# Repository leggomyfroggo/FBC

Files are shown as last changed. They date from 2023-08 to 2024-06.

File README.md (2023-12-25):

# Frog Boy Color
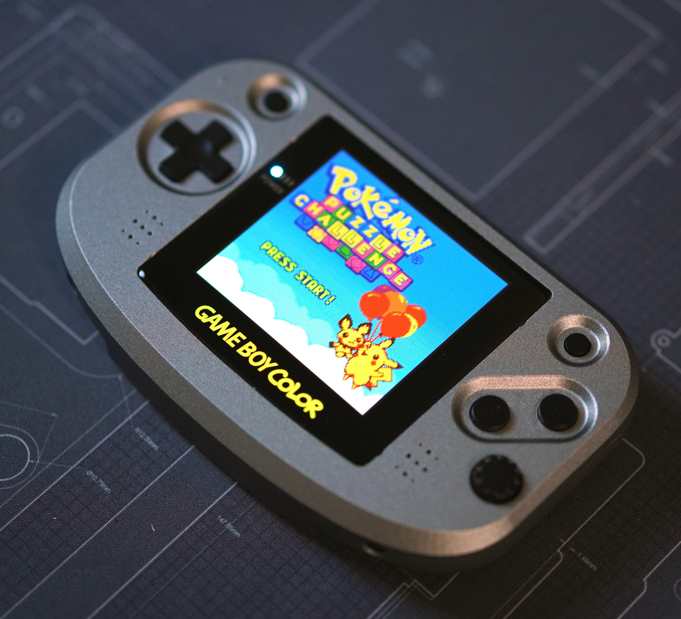
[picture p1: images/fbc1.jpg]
Frog Boy Color

The Frog Boy Color is a reimagining of the Nintendo Game Boy Color, aka the greatest Game Boy ever made. Taking the best parts of a modded GBC -- large screen with correct aspect ratio, no cartridges sticking out, etc -- and marrying them to a horizontal format ala the GBA, the Frog Boy is the realization of exactly the kind of Game Boy I've wanted since I initially jumped into modding. 

Features include:
- All features of the original GBC minus IR -- use of GB/GBC cartridges, link cable, headphone jack, etc.
- Compatibie with popular laminated backlit screen kits from FunnyPlaying and others
- Dual speakers for stereo sound
- Internal battery rechargable via USB-C
- Tactile buttons like the GBA SP
- Two stage battery indicator

The following is a guide on how you can build your very own Frog Boy.

# Attribution
Before getting to the build, it's important to provide attribution to the other project(s) that have in part gone into the Frog Boy Color.
- **[Gekkio/gekkio-kicad-libs](https://github.com/Gekkio/gekkio-kicad-libs)**: The FBC incorporates several of Gekkio's excellent kicad symbols and footprints, including for the CPU, RAM(modified), link port, and cartridge connector(modified). Huge thanks to Gekkio for making these available for others to use!

# Disclaimer/Warning/For the love of God, read this
The Frog Boy is not an easy project, nor is it a professional product, and as such there are some things to keep in mind as you consider building one.

Assembly of the Frog Boy requires intermediate-advanced skills in soldering and electronics tinkering, including:
- Desoldering/soldering of large ICs
- Desoldering of through hole parts
- Soldering of small surface mount devices
- Soldering of leadless ICs, for example the TSP61202
- Proficiency with a multimeter for troubleshooting and validation
This is in no way a project for beginners, and if you don't have experience with the above, I highly recommend starting smaller -- solder practice kits are cheap and easily available.

Along with needing the requisite skills, there is a very real possibility that you will irreparably damage either your donor Game Boy Color, or the resulting Frog Boy. Even the most skilled among us make mistakes, but it's important to keep in mind your own limits to avoid heartache and sorrow.

I am in no way a professional electrical engineer. All of my skills are self taught, or learned from other members of the modding community. While I have taken common sense measures to ensure that the Frog Boy is functional and safe, I can not guarantee that each and every decision made is correct. Build at your own discretion.

In summary, build at your own risk. I am not liable for any damage or injury caused by your insatiable need to build a Game Boy named after an amphibian.

# Recommended Equipment
At a bare minimum, you should have:
- Temperature controlled soldering iron. I recommend the Pinecil as a great entry level option.
- Multimeter for troubleshooting. Any cheap digital multimeter from Amazon should do fine.
- Solder sucker for removing cartridge slot from donor GBC
- No clean flux

I highly recommend also having the following:
- A hot plate or hot air station for the QFN ICs, desoldering parts from GBC, etc
- Solder wick

# Bill of Materials(BOM)
Below is the breakdown of all materials you will need to build a Frog Boy Color.
## Build Components
- **PCB:** The Frog Boy Color uses a fully custom PCB designed to fit within the custom shell while still using many of the original GBC components. The following board parameters should be used:
  - **Layers:** 4-layer
  - **Thickness:** 1mm
  - **Surface finish:** HASL or ENIG
  - **Color:** Whatever you want
  - [**Order from PCBWay**](https://www.pcbway.com/project/shareproject/Frog_Boy_Color_PCB_29101ba1.html)
- **Shell:** The shell for the Frog Boy Color is a fully custom design, and suitable for both resin printing and CNC machining. NOTE: When ordering in resin, there is a risk of the thin areas around the buttons and d-pad to break during fabrication.
  - [**Order from PCBWay**](https://www.pcbway.com/project/shareproject/Frog_Boy_Color_PCB_29101ba1.html)
- **Volume Wheel:** The volume wheel is another custom piece, and is intended to be CNC machined. Resin printing will probably work, but is untested.
  - Step file available in `Accessories` folder so you can get it produced where you wish.
  - [**Order from PCBWay**](https://www.pcbway.com/project/shareproject/Frog_Boy_Color_PCB_29101ba1.html)
- **Battery Clips:** Clips for the batteries to keep them in place. Left and right clips are different, and you'll want one of each. Not stricly necessary, but highly recommended. Should be printed in SLS/MJF nylon.
  - STL files available in `Accessories` folder so you can get them produced where you wish.
  - [**Order from PCBWay**](https://www.pcbway.com/project/shareproject/Frog_Boy_Color_PCB_29101ba1.html)
- **Light pipe:** An optional light pipe can be added for the indicator LEDs to better diffuse them. An STL for this can be found in `Accessories`. This should be printed with clear filament or resin.
  - STL files available in `Accessories` folder so you can get them produced where you wish.
  - [**Order from PCBWay**](https://www.pcbway.com/project/shareproject/Frog_Boy_Color_PCB_29101ba1.html)
- **Screws:** The shell is designed to be put together using 13 x M2 4mm machine screws with flat tops. For builds using a resin printed front shell, the cartridge shield screws can likely be reused for that purpose, which cuts M2 screws required to 9. Options:
  - **450pcs M2 M2.5 M3 Screw Kit:** [From Amazon](https://www.amazon.com/gp/product/B07TDHZJLL/)
- **Cartridge shield:** The metal cartridge shield from the GBC is used here for the same purpose. This can be sourced from your donor console, or from any aftermarket shell.
- **Buttons:** The Frog Boy Color uses buttons from the Game Boy Advance SP, either OEM or aftermarket. You will need a complete set, including the brightness button which is repurposed here as the power button. Some suggested buttons:
  - **FunnyPlaying:** [From RGRS](https://retrogamerepairshop.com/collections/gba-sp-buttons/products/funnyplaying-game-boy-advance-sp-buttons)
  - **RetroCNC(membrane version):** [From RGRS](https://retrogamerepairshop.com/collections/gba-sp-buttons/products/new-game-boy-sp-metal-buttons-by-retrocnc)
- **Membranes:** Similarly, the membranes used are also from the Game Boy Advance SP. You will need two sets of these in order to get two brightness button membranes for start/select. Some suggested membranes:
  - **FunnyPlaying:** [From RGRS](https://retrogamerepairshop.com/collections/gba-sp-buttons/products/funnyplaying-game-boy-advance-sp-silicone-pads)
- **Screen:** The FunnyPlaying laminated Q5 screen -- or a laminated Q5 from another manufacturer with the same total assembly thickness, such as from Gameneissance -- must be used in order to fit within the completed unit. Suggested options:
  - FunnyPlaying laminated Q5 screen + driver board: [From RGRS](https://retrogamerepairshop.com/collections/gbc-displays/products/funnyplaying-game-boy-color-2-0-q5-ips-laminated-backlight-kit)
  - FunnyPlaying laminated Q5 screen only: [From RGRS](https://retrogamerepairshop.com/collections/gbc-displays/products/funnyplaying-game-boy-color-2-0-q5-ips-laminated-lcd-replacement-screen-only)
- **Screen driver board:** For the screen driver board, you have two options:
  - FunnyPlaying GBC Retro Pixel 2.0 laminated IPS kit. This is the simplest option, as it can be purchased with the screen, and can be installed as is. The caveat is that the touch sensor will not work if you choose to install in an aluminum shell, and you'll need to connect the button controls.
    - FunnyPlaying driver board: [From FunnyPlaying](https://funnyplaying.com/products/gbc-retro-pixel-ips-2-0-replacement-ribbon)
  - Super OSD Retro Pixel IPS kit. An alternative to the FunnyPlaying kit with additional options. The downside is that you generally can not purchase it with a suitable laminated screen, and the board-to-board ribbon cable is rather stiff, which can cause assembly issues. The latter can be mitigated by using the custom replacement found under the `Accessories` folder.
    - Super OSD kit(for driver board only, screen too thick): [From RGRS](https://retrogamerepairshop.com/collections/gbc-displays/products/game-boy-color-laminated-q5-xl-ips-backlight-with-osd)
- **Batteries:** The Frog Boy Color can be built with either one or two 802040 LiPo pouch cells. One battery is a simpler arrangement, at the expense of battery life. Two batteries are more complicated, as you'll be required to balance two cells prior to assembly, but with the benefit of roughly double the battery life.

  I also highly recommend printing/ordering the optional battery clips in the `Accessories` folder. They register with holes on each side of the PCB, and provide a nice clip and standoff for each of the batteries. Can be cheaply printed in SLS nylon from JLCPCB, PCBWay, etc.

  NOTE: LiPo batteries can be dangerous if mishandled. NEVER use unprotected cells. It's always safer to use one cell if you're unsure of your ability to properly balance two cells.
  Purchase options:
  - 802040 cell: [From AliExpress](https://www.aliexpress.us/item/3256802244810488.html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)
 
## Shell Ordering Notes
### CNC Machining
- When ordering the front and back shell, make sure you check the box indicating that you need tapped threads. Thread tapping information is already included in the technical drawings.
- Colors for aluminum shells are found under certain "Surface finish" options, such as anodizing.
### Resin Printing
- In the order notes, ask for the shell to be "printed at 99.5% scale on all axes". Resin has a tendency to shrink as it cures, and printers will often overscale to account for this.
- For transparent resin, colors can be selected when choosing dying from the "Surface finish" options.

## PCB Components
- **Harvested GBC Parts:** You will need a donor GBC of revision CPU-05 or before -- CPU-06 revisions will NOT work -- that retains the following components in working order:
  - CPU
  - RAM
  - Crystal
  - Link port
  - Cartridge slot
- **New parts:** The full BOM for the Frog Boy Color be found in the repo, `BOM.xlsx`. Most parts are available from Mouser through a shared project. USB-C connector is available from LCSC. Most parts should be available from most other large distributors in case you want to build out your own cart. Some options:
  - Mouser: [Shared Project](https://www.mouser.com/ProjectManager/ProjectDetail.aspx?AccessID=2927c2105f)
  - LCSC: [USB-C connector](https://www.lcsc.com/product-detail/USB-Connectors_Korean-Hroparts-Elec-TYPE-C-31-M-12_C165948.html)

# Recommended Assembly Procedure
At this point, if you feel confident in your skills, you can proceed with the complete build from PCB to final unit -- assembly after building the PCB is relatively straightforward.

However, I've devised an assembly strategy after assembling a few units that will allow you to check your work along the way, and I highly recommend that you follow along.
## PCB Assembly
### 1. Assembling and testing power circuitry
The power circuitry consists of regulated 5V(TPS61202) and 3.3V(MCP1799T) rails. Start by populating all of the components in the red box on this diagram:

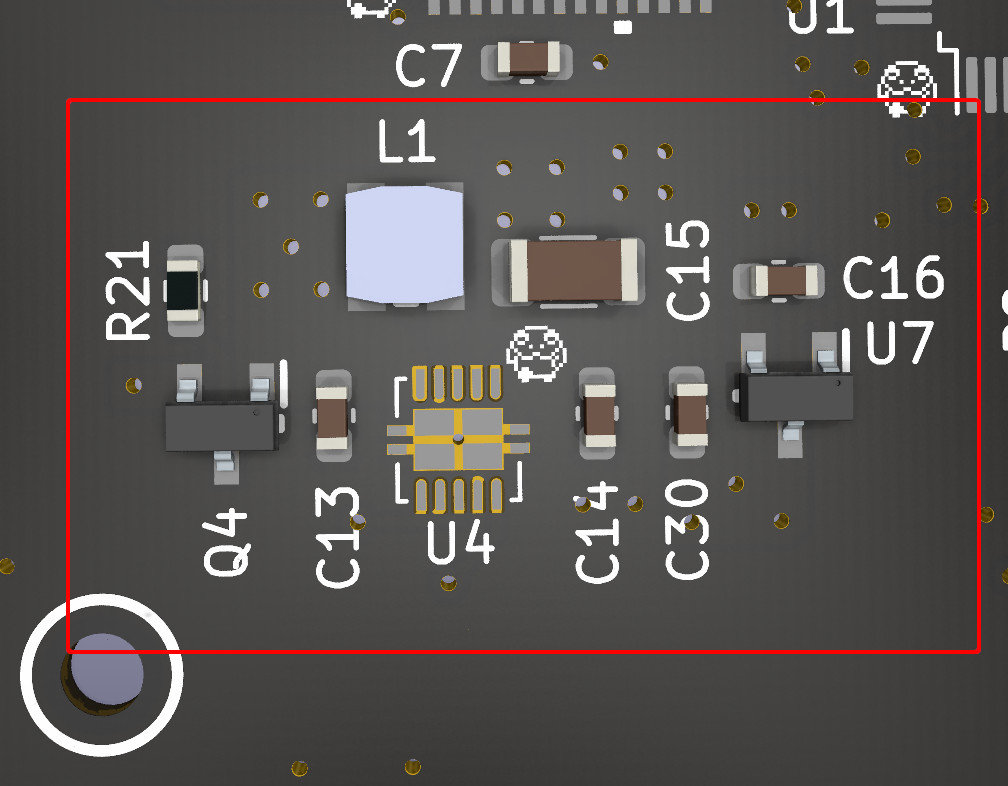
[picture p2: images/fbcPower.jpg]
Power circuitry


You'll then want to test these components to verify that the 5V and 3.3V rails are working correctly. Start by connecting one of your LiPo cells to the VCC1 test pad and pin 32(GND) on the cart slot -- I highly recommend using a multimeter in continuity mode to confirm that these points are not shorted.

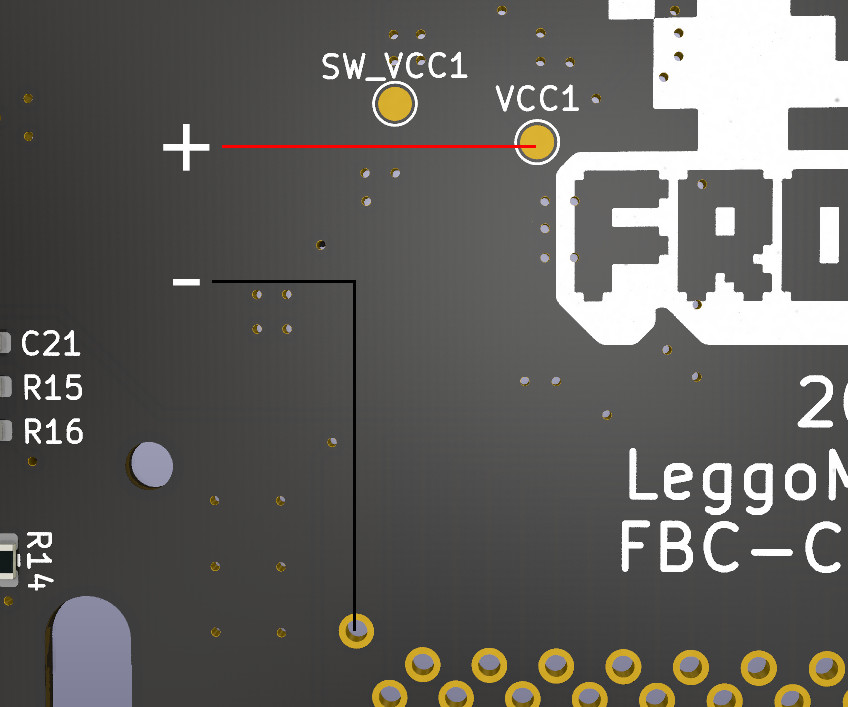
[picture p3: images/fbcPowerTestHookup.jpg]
Battery hook up points


Next, with your meter in DC voltage mode, do the following two tests to verify that the 5V and 3.3V rails are outputting the expected voltage.

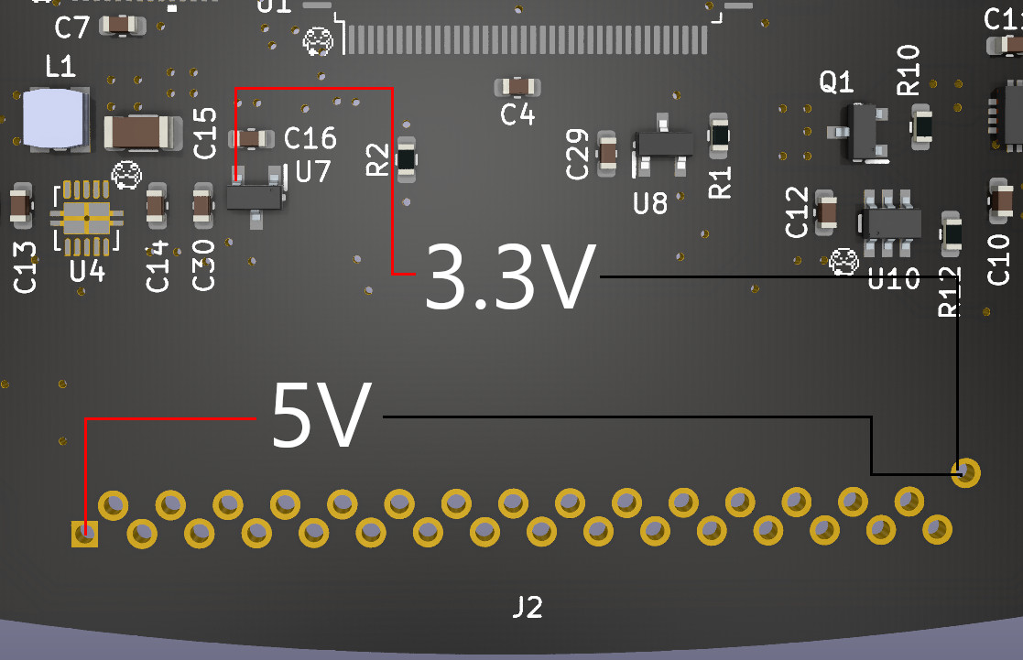
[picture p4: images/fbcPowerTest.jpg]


If everything looks good, you're ready to proceed to the next step.
### 2. Assembling and testing battery charging circuitry
At the heart of the battery charging circuit is the BQ24072TRGTR, which provides both battery charging and power path management -- the latter allows for simultaneous charge and play. Alongside the charging circuitry is a soft latching power circuit, that allows for the use of a momentary push button switch to control power, in contrast to the GBC's slide switch.

Again, start by populating the components indicated below:

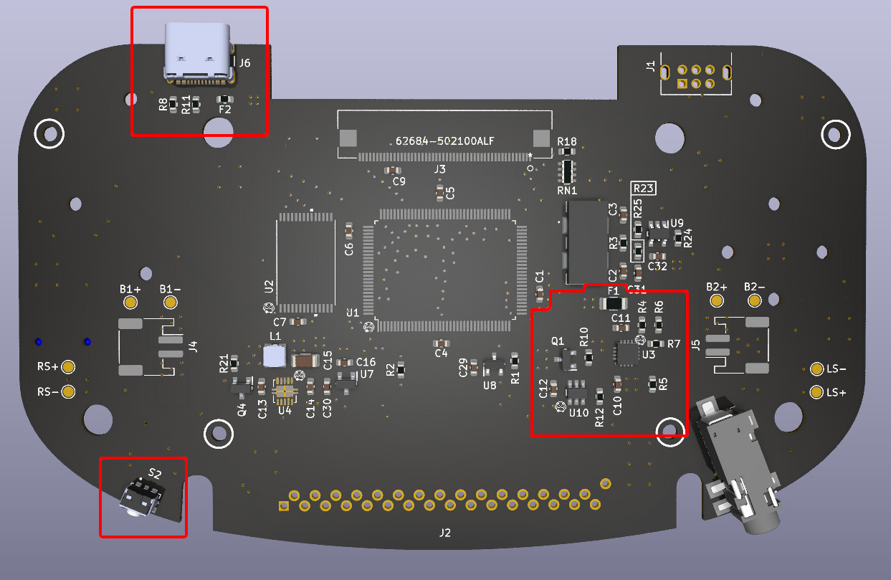
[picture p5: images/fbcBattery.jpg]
Battery and power switch circuitry


Now that the battery circuitry is assembled, a battery can be connected to one of the designated spots for integration testing of the entire power system, e.g B1+ and B1-. At this point, consider the system live any time a battery is connected -- do not do any soldering without first disconnecting all batteries. 

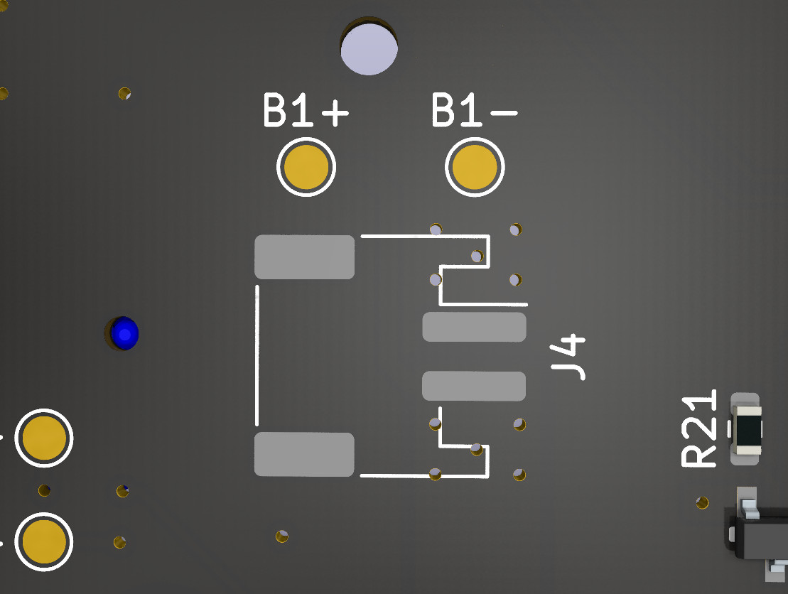
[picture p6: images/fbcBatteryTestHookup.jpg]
Hook up spot for battery 1


Once a battery is connected, put your meter into DC voltage mode and perform the following tests. 

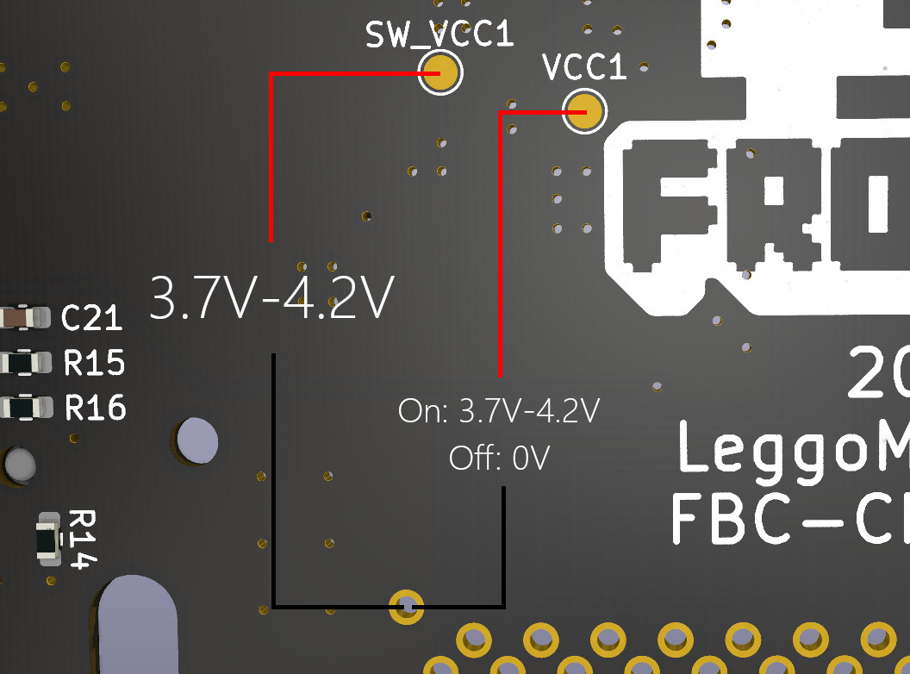
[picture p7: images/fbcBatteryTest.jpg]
Tests for verifying the battery circuitry


For context, SW_VCC1 is live regardless of power state, and should read roughly the same voltage as the battery at all times. VCC1 is the output of the power switch, and should read 0V when the system is off, and roughly battery voltage when the system is on. Press the power switch to cycle between off and on and take measurements to verify that VCC1 reads the correct values. Now is also a good time to verify that your 5V and 3.3V power rails come up when the system is on.

At this point, assuming everything reads correctly, you can be reasonably certain nothing will get fried, and can proceed to the next step. We'll verify battery charging at a later time.

### 3. Installing core GBC pieces
At this point we get to the heart of the system, which is composed of the CPU, RAM, crystal, reset circuitry, display connector, and their support circuitry. The following components should be populated:

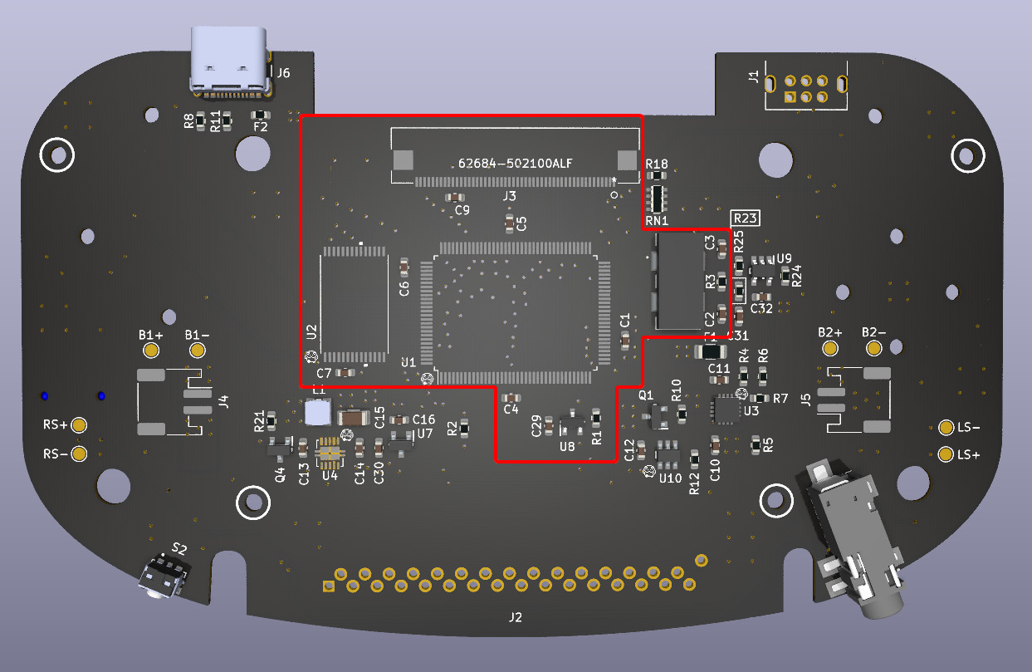
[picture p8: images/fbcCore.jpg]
Core components


With the core components populated at this point, you should now have a semi-functional Frog Boy. To test, connect a battery like in step 2, plug in your screen kit of choice, and power on the system. You should be greeted with the iconic GBC boot screen.

#### Troubleshooting:
This is where things might start to go off the rails, given the number of pins on each of these components. Even one floating pin can cause noticeable problems. Here are some potential problems and solutions.

- **Black screen:** Might indicate a short or floating pin on any of the installed components. Verify all of the power measurements from steps 1 and 2 to rule out major shorts. Double check all of the CPU, RAM, and display connector pins for bridges and floating pins.
- **White screen:** Might indicate a problem with the reset circuitry. Make sure there are no floating pins on U8, C29, R1, or CPU pin 35.
- **Weird colors on screen:** Indicative of bridged/floating pins on the RAM, top of the CPU, or display connector. Go over each connection to make sure there are no bridges or floating pins.

### 4. Assembly of remaining circuitry
With the QFNs and large ICs out of the way, the remainder of the PCB assembly is relatively straightforward, and I have little more to offer in terms of order of assembly or testing.

The remaining bits are a pair of LM4875 audio amplifiers for the stereo audio and the associated circuitry for that, the battery indicator circuit, the cartridge port, and the link port circuitry. Except for testing, speakers should not be connected until final unit assembly.

Battery charging can be tested at this point by connecting a battery to the proper spot on the board, and then plugging in a USB-C cable. If charging is working correctly, you should see the charge indicator light on the front of the board turn on and stay on during the duration of charging.

One thing I do recommend is to install the tac switches _last_. It's highly advisable that you give the entire board a good clean with IPA to remove any residual flux or other gunk. Doing so with the tac switches installed may carry crap into said switches, which can cause problems with their responsiveness.

### Troubleshooting:
- **Charge light doesn't come on:** Verify that the 5V from USB makes it to the right side of F2. If it does, check the soldering on the charge indicator LED and the charge IC. If there's still no charge indicator, double check that the LED is working using a multimeter in diode mode. If all else fails, the charge IC might be dead.
- **Charge light comes on that shuts off immediately:** Charge IC is most likely dead. Give it a reflow prior to replacing, just to be certain.

## Final Assembly
Assembly of the final unit after successfully building the PCB is relatively straightforward, but here are some component specific pointers.

### Speakers
In contrast to OEM Game Boys, speaker polarity matters in the case of the FBC, at least between the two speakers. The same terminal on each speaker should connect to the same polarity speaker pad on the motherboard, e.g. left to positive, right to negative. If the speakers are connected with polarity reversed relative to eachother, destructive interference will cancel out much of the audio.

To keep the speakers in place before placing the PCB, I recommend placing a thin piece of double sided tape to the front edge of each speaker.

### Cartridge shield
With the current shell design in some materials, the cartridge shield may cause cartridges to not sit perfectly flush with the back of the unit. This will be fixed in a future iteration of the shell, but if you encounter this issue, simply back off the screws on the cartridge shield about 1/2 turn so it's slightly loose.

### Screen kit controls
I highly recommend connecting the controls for whatever screen kit you've chosen to the button test points on the front of the FBC board. While touch sensors in general work okay in plastic shells, they can still be flakey, and don't work at all in metal shells. It's recommended to cut off the touch sensor in this case to prevent accidental triggers.

### Assembly video
To get an overview of the assembly process, check out my video about the Frog Boy Color: [YouTube](https://youtu.be/_rRCEbcjiho)

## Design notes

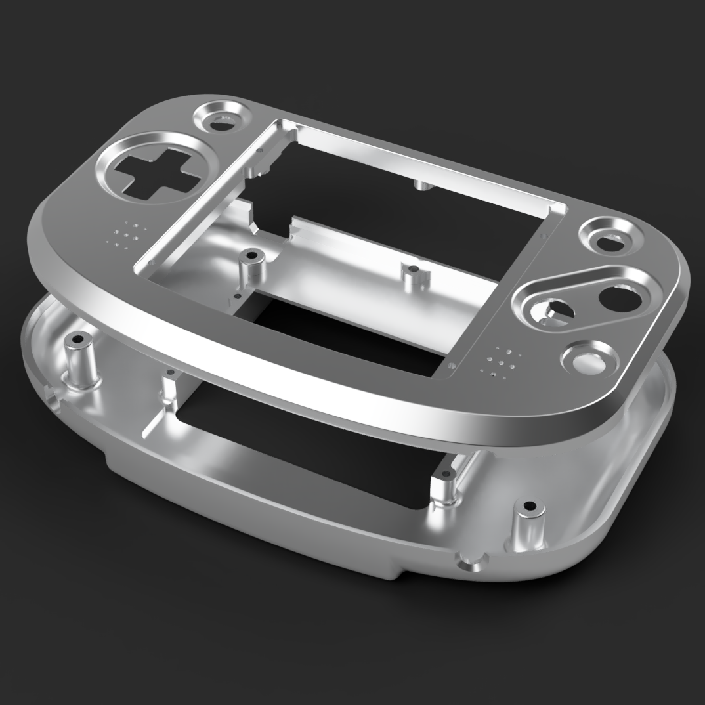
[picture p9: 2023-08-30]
images/fbcShell.png

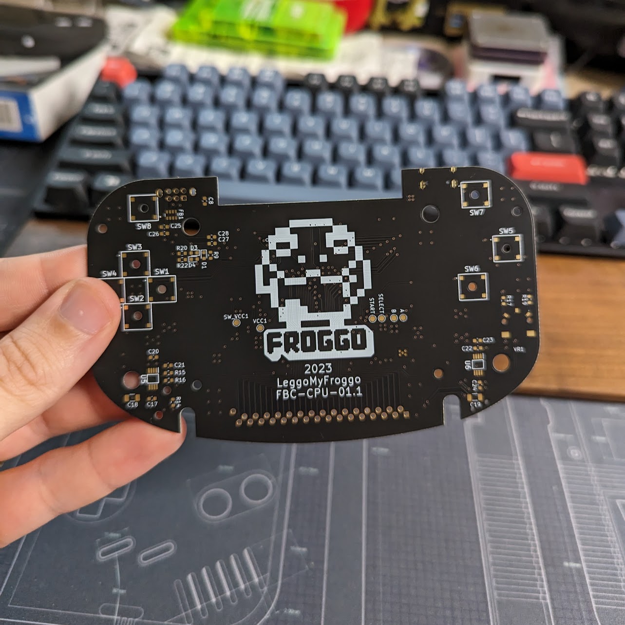
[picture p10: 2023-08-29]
images/fbcPCB.jpg

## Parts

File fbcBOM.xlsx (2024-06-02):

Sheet: v2
Frog Boy Color BOM for board revision v2
Designator(s) | Quantity | Value/Part Number | Package | Notes | URL
Battery | 2024-01-02 | - | 802040 | Only one battery is necessary. When using two, balance charge prior to installation. | https://www.aliexpress.us/item/3256802244810488.html
C11,C10 | 2 | 4.7uF | 0603 |  | https://www.mouser.com/ProductDetail/81-GRM188Z71A475ME5D
C13 | 1 | 10uF | 0603 |  | https://www.mouser.com/ProductDetail/81-GRM188Z71A106KA3D
C15 | 1 | 22uF | 1206 |  | https://www.mouser.com/ProductDetail/581-1206ZC226MAT2A
C18,C19 | 2 | 100uF | 1206 | Use tantalum capacitors. 22uF MLCC can be substituted in a pinch | https://www.mouser.com/ProductDetail/581-TLJA107M10R1400
C2 | 1 | 18pF | 0603 |  | https://www.mouser.com/ProductDetail/581-06035A180J
C22,C16,C21,C31,C14,C24,C30,C17,C29 | 9 | 1uF | 0603 |  | https://www.mouser.com/ProductDetail/581-0603YC105KAT2A
C23,C20 | 2 | 0.22uF | 0603 |  | https://www.mouser.com/ProductDetail/603-AC0603X7R9BB224
C25 | 1 | 22pF | 0603 |  | https://www.mouser.com/ProductDetail/581-06035C220JAT2A
C26,C27,C28 | 3 | 100pF | 0603 |  | https://www.mouser.com/ProductDetail/581-0603YC101KAT2A
C3 | 1 | 27pF | 0603 |  | https://www.mouser.com/ProductDetail/581-06035A270J
C7,C9,C4,C1,C5,C6,C32,C12,C8 | 9 | 100nF | 0603 |  | https://www.mouser.com/ProductDetail/581-06035C104KAT2A
D4,D3,D1 | 3 | LED | 0603 | D1: Charge, D3: High batt, D4: Low batt
F1 | 1 | 2.5A | 1206 |  | https://www.mouser.com/ProductDetail/667-ERB-RG2R50V
F2 | 1 | 1A | 0603 |  | https://www.mouser.com/ProductDetail/594-MFU0603FF01000P1
FB1 | 1 | FBx4 | 1206 | Can harvest from CGB-CPU-04 and earlier: FB1 | https://www.mouser.com/ProductDetail/81-BLA3216A601SG4
J1 | 1 | Link port | - | Harvest from GBC/GBP
J2 | 1 | Cartridge slot | - | Harvest from GBC
J3 | 1 | 62684-502100ALF | 62684-502100ALF | Can harvest from GBC: P2 | https://www.mouser.com/ProductDetail/649-62684-502100ALF
J6 | 1 | USB4105-GF-A | GCT_USB4105-GF-A |  | https://www.mouser.com/ProductDetail/640-USB4105-GF-A
J7 | 1 | SJ2-3593D-SMT-TR | SJ23593DSMTTR | Headphone jack | https://www.mouser.com/ProductDetail/490-SJ2-3593D-SMT-TR
L1 | 1 | VLS3012HBX-2R2M-N | VLS3012 |  | https://www.mouser.com/ProductDetail/810-VLS3012HBX2R2M-N
Q1,Q4 | 2 | DMP6350SQ-7 | SOT-23 |  | https://www.mouser.com/ProductDetail/621-DMP6350SQ-7
R1,R10,R12 | 3 | 10K | 0603 |  | https://www.mouser.com/ProductDetail/71-CRCW0603-5.1K-E3
R11,R8,R19 | 3 | 5.1K | 0603 |  | https://www.mouser.com/ProductDetail/71-CRCW0603-5.1K-E3
R15 | 1 | 100K | 0603 |  | https://www.mouser.com/ProductDetail/603-RC0603FR-07100KL
R17 | 1 | 15K | 0603 |  | https://www.mouser.com/ProductDetail/Bourns/CR0603-FX-1502ELF
R18,R20 | 2 | 5.6K | 0603 |  | https://www.mouser.com/ProductDetail/71-CRCW0603-5.6K-E3
R2 | 1 | 100 | 0603 |  | https://www.mouser.com/ProductDetail/603-RC0603FR-07100RL
R21,R14 | 2 | 150 | 0603 |  | https://www.mouser.com/ProductDetail/603-RT0603FRE13150RL
R23 | 1 | 430K | 0603 |  | https://www.mouser.com/ProductDetail/603-RC0603FR-13430KL
R24 | 1 | 20K | 0603 |  | https://www.mouser.com/ProductDetail/603-RC0603FR-0720KL
R25 | 1 | 47K | 0603 |  | https://www.mouser.com/ProductDetail/603-RC0603FR-0747KL
R3 | 1 | 1.5M | 0603 |  | https://www.mouser.com/ProductDetail/71-CRCW0603-1.5M-E3
R4 | 1 | 200K | 0603 |  | https://www.mouser.com/ProductDetail/603-RC0603FR-07200KL
R5,R22 | 2 | 3.3K | 0603 |  | https://www.mouser.com/ProductDetail/71-CRCW0603-3.3K-E3
R6, R16 | 2 | 49.9K | 0603 |  | https://www.mouser.com/ProductDetail/71-CRCW0603-49.9K-E3
R7 | 1 | 2.2K | 0603 |  | https://www.mouser.com/ProductDetail/71-CRCW0603-2.2K-E3
R9 | 1 | 1K | 0603 |  | https://www.mouser.com/ProductDetail/652-CR0603FX-1001ELF
X1 | 1 | 8.388608MHz | 5x7Crystal | Choose one of X1 or Y1 | https://www.aliexpress.us/item/3256805403138830.html
RN1 | 1 | 270x4 | 1206 | Can harvest from GBC: RA3 | https://www.mouser.com/ProductDetail/603-TC164-JR-07270RL
S2 | 1 | SKRTLAE010 | SW_SKRTLAE010 |  | https://www.mouser.com/ProductDetail/688-SKRTLA
Speaker | 2 | OWS-111535LA-8H | - |  | https://www.digikey.com/en/products/detail/ole-wolff-electronics-inc/OWS-111535LA-8H/17634911
SW8,SW7,SW5,SW3,SW1,SW2,SW4,SW6 | 8 | SKRRAAE010 | - |  | https://www.mouser.com/ProductDetail/688-SKRRAA
U1 | 1 | CGB CPU | - | Harvest from GBC
U10 | 1 | MAX16054AZT+T | SOT-23-6 |  | https://www.mouser.com/ProductDetail/700-MAX16054AZTT
U2 | 1 | CGB RAM | - | Harvest from GBC
U3 | 1 | BQ24072TRGTR | VQFN-16 |  | https://www.mouser.com/ProductDetail/595-BQ24072TRGTR
U4 | 1 | TPS61202DSC | WSON-10 |  | https://www.mouser.com/ProductDetail/595-TPS61202DSCR
U5,U6 | 2 | LM4875MM_NOPB | VSSOP-8 |  | https://www.mouser.com/ProductDetail/926-LM4875MM-NOPB
U7 | 1 | MCP1700T-3302E/TT | SOT-23 |  | https://www.mouser.com/ProductDetail/579-MCP1700T3302E-TT
U8 | 1 | TLV803EB33VDBZR | SOT-23 |  | https://www.mouser.com/ProductDetail/595-TLV803EB33VDBZR
U9 | 1 | TLV3201AIDBVR | SOT-23-5 |  | https://www.mouser.com/ProductDetail/595-TLV3201AIDBVR
VR1 | 1 | RK08H113003Q | RK08H113003Q |  | https://www.mouser.com/ProductDetail/688-RK08H113003Q
Y1 | 1 | 8.388608MHz | - | Choose one of X1 or Y1

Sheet: v1.3
Frog Boy Color BOM for board revision v1.3
Designator(s) | Quantity | Value/Part Number | Package | Notes | URL
Battery | 2023-01-02 | - | 802040 | Only one battery is necessary. When using two, balance charge prior to installation. | https://www.aliexpress.us/item/3256802244810488.html
C11,C10 | 2 | 4.7uF | 0603 |  | https://www.mouser.com/ProductDetail/81-GRM188Z71A475ME5D
C13 | 1 | 10uF | 0603 |  | https://www.mouser.com/ProductDetail/81-GRM188Z71A106KA3D
C15 | 1 | 22uF | 1206 | C15 can alternatively be replaced with 100uF tantalum capacitor | https://www.mouser.com/ProductDetail/581-1206ZC226MAT2A
C16,C31,C14,C30,C29,C22,C21,C24,C17 | 9 | 1uF | 0603 |  | https://www.mouser.com/ProductDetail/581-0603YC105KAT2A
C18,C19 | 2 | 100uF | 1206 | Use tantalum capacitors. 22uF MLCC can be substituted in a pinch | https://www.mouser.com/ProductDetail/581-TLJA107M10R1400
C2 | 1 | 18pF | 0603 |  | https://www.mouser.com/ProductDetail/581-06035A180J
C23,C20 | 2 | 0.22uF | 0603 |  | https://www.mouser.com/ProductDetail/603-AC0603X7R9BB224
C25 | 1 | 22pF | 0603 |  | https://www.mouser.com/ProductDetail/581-06035C220JAT2A
C26,C27,C28 | 3 | 100pF | 0603 |  | https://www.mouser.com/ProductDetail/581-0603YC101KAT2A
C3 | 1 | 27pF | 0603 |  | https://www.mouser.com/ProductDetail/581-06035A270J
C7,C9,C4,C1,C5,C6,C32,C12,C8 | 9 | 100nF | 0603 |  | https://www.mouser.com/ProductDetail/581-06035C104KAT2A
D4,D3,D1 | 3 | LED | 0603 | D1: Charge, D3: High batt, D4: Low batt
F1 | 1 | 2.5A, ERB-RG2R50V | 1206 |  | https://www.mouser.com/ProductDetail/667-ERB-RG2R50V
F2 | 1 | 1A | 0603 |  | https://www.mouser.com/ProductDetail/594-MFU0603FF01000P1
FB1 | 1 | FBx4 | 1206 | Can harvest from CGB-CPU-04 and earlier: FB1 | https://www.mouser.com/ProductDetail/81-BLA3216A601SG4
J1 | 1 | Link port | - | Harvest from GBC/GBP
J2 | 1 | Cartridge slot | - | Harvest from GBC
J3 | 1 | 62684-502100ALF | 62684-502100ALF | Can harvest from GBC: P2 | https://www.mouser.com/ProductDetail/649-62684-502100ALF
J5,J4 | 2 | JST PH 2-pin | - | OPTIONAL: Reduces battery size that can be used to 602040
J6 | 1 | USB4105-GF-A | GCT_USB4105-GF-A |  | https://www.lcsc.com/product-detail/USB-Connectors_Korean-Hroparts-Elec-TYPE-C-31-M-12_C165948.html
J7 | 1 | SJ2-3593D-SMT-TR | SJ23593DSMTTR | Headphone jack | https://www.mouser.com/ProductDetail/490-SJ2-3593D-SMT-TR
L1 | 1 | VLS3012HBX-2R2M-N | VLS3012 |  | https://www.mouser.com/ProductDetail/810-VLS3012HBX2R2M-N
Q1,Q4 | 2 | DMP6350SQ-7 | SOT-23 |  | https://www.mouser.com/ProductDetail/621-DMP6350SQ-7
R1,R10,R12 | 3 | 10K | 0603 |  | https://www.mouser.com/ProductDetail/71-CRCW0603-5.1K-E3
R15 | 1 | 100K | 0603 |  | https://www.mouser.com/ProductDetail/603-RC0603FR-07100KL
R17 | 1 | 15K | 0603 |  | https://www.mouser.com/ProductDetail/Bourns/CR0603-FX-1502ELF
R18,R20 | 2 | 5.6K | 0603 |  | https://www.mouser.com/ProductDetail/71-CRCW0603-5.6K-E3
R2 | 1 | 100 | 0603 |  | https://www.mouser.com/ProductDetail/603-RC0603FR-07100RL
R21,R14 | 2 | 150 | 0603 |  | https://www.mouser.com/ProductDetail/603-RT0603FRE13150RL
R23 | 1 | 430K | 0603 |  | https://www.mouser.com/ProductDetail/603-RC0603FR-13430KL
R24 | 1 | 20K | 0603 |  | https://www.mouser.com/ProductDetail/603-RC0603FR-0720KL
R25 | 1 | 47K | 0603 |  | https://www.mouser.com/ProductDetail/603-RC0603FR-0747KL
R3 | 1 | 1.5M | 0603 |  | https://www.mouser.com/ProductDetail/71-CRCW0603-1.5M-E3
R4 | 1 | 200K | 0603 |  | https://www.mouser.com/ProductDetail/603-RC0603FR-07200KL
R5,R22 | 2 | 3.3K | 0603 |  | https://www.mouser.com/ProductDetail/71-CRCW0603-3.3K-E3
R6, R16 | 2 | 49.9K | 0603 |  | https://www.mouser.com/ProductDetail/71-CRCW0603-49.9K-E3
R7 | 1 | 2.2K | 0603 |  | https://www.mouser.com/ProductDetail/71-CRCW0603-2.2K-E3
R8, R11, R19 | 3 | 5.1K | 0603 |  | https://www.mouser.com/ProductDetail/71-CRCW0603-5.1K-E3
R9 | 1 | 1K | 0603 |  | https://www.mouser.com/ProductDetail/652-CR0603FX-1001ELF
RN1 | 1 | 270x4 | 1206 | Can harvest from GBC: RA3 | https://www.mouser.com/ProductDetail/603-TC164-JR-07270RL
S2 | 1 | SKRTLAE010 | - |  | https://www.mouser.com/ProductDetail/688-SKRTLA
Speaker | 2 | CMS-151103-088SP | - |  | https://www.mouser.com/ProductDetail/490-CMS-151103-088SP
SW8,SW7,SW5,SW3,SW1,SW2,SW4,SW6 | 8 | SKRRAAE010 | - |  | https://www.mouser.com/ProductDetail/688-SKRRAA
U1 | 1 | CGB CPU | - | Harvest from GBC
U10 | 1 | MAX16054AZT+T | SOT-23-6 |  | https://www.mouser.com/ProductDetail/700-MAX16054AZTT
U2 | 1 | CGB RAM | - | Harvest from GBC
U3 | 1 | BQ24072TRGTR | VQFN-16 |  | https://www.mouser.com/ProductDetail/595-BQ24072TRGTR
U4 | 1 | TPS61202DSC | WSON-10 |  | https://www.mouser.com/ProductDetail/595-TPS61202DSCR
U5,U6 | 2 | LM4875MM_NOPB | VSSOP-8 |  | https://www.mouser.com/ProductDetail/926-LM4875MM-NOPB
U7 | 1 | MCP1700T-3302E/TT | SOT-23 |  | https://www.mouser.com/ProductDetail/579-MCP1700T3302E-TT
U8 | 1 | TLV803EB33VDBZR | SOT-23 |  | https://www.mouser.com/ProductDetail/595-TLV803EB33VDBZR
U9 | 1 | TLV3201AIDBVR | SOT-23-5 |  | https://www.mouser.com/ProductDetail/595-TLV3201AIDBVR
VR1 | 1 | RK08H113003Q | RK08H113003Q |  | https://www.mouser.com/ProductDetail/688-RK08H113003Q
Y1 | 1 | 8.388608MHz | - | Harvest from GBC

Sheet: <=V1.2
Frog Boy Color BOM for board revision <= v1.2 |  |  |  |  |  | Frog Boy Color BOM for board revision v1.3 | Frog Boy Color BOM for board revision v1.3 | Frog Boy Color BOM for board revision v1.3
Designators | Quantity | Value/Part Number | Package | Notes | URL
C11,C10 | 2 | 4.7uF | 0603 |  | https://www.mouser.com/ProductDetail/81-GRM188Z71A475ME5D
C12,C15 | 2 | 22uF | 1206 | C15 can alternatively be replaced with 100uF tantalum capacitor | https://www.mouser.com/ProductDetail/581-1206ZC226MAT2A
C13 | 1 | 10uF | 0606 |  | https://www.mouser.com/ProductDetail/81-GRM188Z71A106KA3D
C16,C31,C14,C30,C29,C22,C21,C24,C17 | 9 | 1uF | 0603 |  | https://www.mouser.com/ProductDetail/581-0603YC105KAT2A
C18,C19 | 2 | 100uF | 1206 | Use tantalum capacitors. 22uF MLCC can be substituted in a pinch | https://www.mouser.com/ProductDetail/581-TLJA107M10R1400
C2 | 1 | 18pF | 0603 |  | https://www.mouser.com/ProductDetail/581-06035A180J
C23,C20 | 2 | 0.22uF | 0603 |  | https://www.mouser.com/ProductDetail/603-AC0603X7R9BB224
C25 | 1 | 22pF | 0603 |  | https://www.mouser.com/ProductDetail/581-06035C220JAT2A
C26,C27,C28 | 3 | 100pF | 0603 |  | https://www.mouser.com/ProductDetail/581-0603YC101KAT2A
C3 | 1 | 27pF | 0603 |  | https://www.mouser.com/ProductDetail/581-06035A270J
C7,C9,C4,C1,C5,C6,C32,C8 | 8 | 100nF | 0603 |  | https://www.mouser.com/ProductDetail/581-06035C104KAT2A
D4,D3,D1 | 3 | LED | 0603 | D1: Charge, D3: High batt, D4: Low batt
F1 | 1 | 2.5A, ERB-RG2R50V | 1206 |  | https://www.mouser.com/ProductDetail/667-ERB-RG2R50V
F2 | 1 | 1A | 0603 |  | https://www.mouser.com/ProductDetail/594-MFU0603FF01000P1
FB1 | 1 | FBx4 | 1206 | Can harvest from CGB-CPU-04 and earlier: FB1 | https://www.mouser.com/ProductDetail/81-BLA3216A601SG4
J1 | 1 | Link port | - | Harvest from GBC/GBP
J2 | 1 | Cartridge slot | - | Harvest from GBC
J3 | 1 | 62684-502100ALF | 62684-502100ALF | Can harvest from GBC: P2 | https://www.mouser.com/ProductDetail/649-62684-502100ALF
J5,J4 | 2 | JST PH 2-pin | - | Optional | https://www.mouser.com/ProductDetail/485-1769
J6 | 1 | TYPE-C-31-M-12 | - |  | https://www.lcsc.com/product-detail/USB-Connectors_Korean-Hroparts-Elec-TYPE-C-31-M-12_C165948.html
J7 | 1 | SJ2-3593D-SMT-TR | SJ23593DSMTTR |  | https://www.mouser.com/ProductDetail/490-SJ2-3593D-SMT-TR
L1 | 1 | VLS3012HBX-2R2M-N | VLS3012 |  | https://www.mouser.com/ProductDetail/810-VLS3012HBX2R2M-N
Q1,Q4 | 2 | DMP6350SQ-7 | SOT-23 |  | https://www.mouser.com/ProductDetail/621-DMP6350SQ-7
Q3,Q2 | 2 | SI2312BDS-T1-BE3 | SOT-23 |  | https://www.mouser.com/ProductDetail/78-SI2312BDS-T1-BE3
R1 | 1 | 10K | 0603 |  | https://www.mouser.com/ProductDetail/71-CRCW0603-5.1K-E3
R11,R8 | 2 | 5.1K | 0603 |  | https://www.mouser.com/ProductDetail/71-CRCW0603-5.1K-E3
R13,R12,R10,R15 | 4 | 100K | 0603 |  | https://www.mouser.com/ProductDetail/603-RC0603FR-07100KL
R17 | 1 | 10k | 0603 |  | https://www.mouser.com/ProductDetail/603-RC0603FR-0710KL
R18,R20 | 2 | 5.6K | 0603 |  | https://www.mouser.com/ProductDetail/71-CRCW0603-5.6K-E3
R2 | 1 | 100 | 0603 |  | https://www.mouser.com/ProductDetail/603-RC0603FR-07100RL
R21,R14 | 2 | 150 | 0603 |  | https://www.mouser.com/ProductDetail/603-RT0603FRE13150RL
R23 | 1 | 430K | 0605 |  | https://www.mouser.com/ProductDetail/603-RC0603FR-13430KL
R24 | 1 | 20K | 0603 |  | https://www.mouser.com/ProductDetail/603-RC0603FR-0720KL
R25 | 1 | 47K | 0603 |  | https://www.mouser.com/ProductDetail/603-RC0603FR-0747KL
R3 | 1 | 1.5M | 0603 |  | https://www.mouser.com/ProductDetail/71-CRCW0603-1.5M-E3
R4 | 1 | 200K | 0603 |  | https://www.mouser.com/ProductDetail/603-RC0603FR-07200KL
R5,R22 | 2 | 3.3K | 0603 |  | https://www.mouser.com/ProductDetail/71-CRCW0603-3.3K-E3
R6, R16 | 2 | 49.9K | 0603 |  | https://www.mouser.com/ProductDetail/71-CRCW0603-49.9K-E3
R7, R19 | 2 | 2.2K | 0603 |  | https://www.mouser.com/ProductDetail/71-CRCW0603-2.2K-E3
R9 | 1 | 1K | 0603 |  | https://www.mouser.com/ProductDetail/652-CR0603FX-1001ELF
RN1 | 1 | 270x4 | 1206 | Can harvest from GBC: RA3 | https://www.mouser.com/ProductDetail/603-TC164-JR-07270RL
S2 | 1 | SKRTLAE010 | - |  | https://www.mouser.com/ProductDetail/688-SKRTLA
SW8,SW7,SW5,SW3,SW1,SW2,SW4,SW6 | 8 | SKRRAAE010 | - |  | https://www.mouser.com/ProductDetail/688-SKRRAA
U1 | 1 | CGB CPU | - | Harvest from GBC
U2 | 1 | CGB RAM | - | Harvest from GBC
U3 | 1 | BQ24072TRGTR | VQFN-16 |  | https://www.mouser.com/ProductDetail/595-BQ24072TRGTR
U4 | 1 | TPS61202DSC | WSON-10 |  | https://www.mouser.com/ProductDetail/595-TPS61202DSCR
U5,U6 | 2 | LM4875MM_NOPB | VSSOP-8 |  | https://www.mouser.com/ProductDetail/926-LM4875MM-NOPB
U7 | 1 | MCP1799T-3302H_TT | SOT-23 |  | https://www.mouser.com/ProductDetail/579-CP1799T-3302H-TT
U8 | 1 | TLV803EB33VDBZR | SOT-23 |  | https://www.mouser.com/ProductDetail/595-TLV803EB33VDBZR
U9 | 1 | TLV3201AIDBVR | SOT-23-5 |  | https://www.mouser.com/ProductDetail/595-TLV3201AIDBVR
VR1 | 1 | RK08H113003Q | RK08H113003Q |  | https://www.mouser.com/ProductDetail/688-RK08H113003Q
Y1 | 1 | 8.388608MHz | - | Harvest from GBC
Speaker | 2 | CMS-151103-088SP | - |  | https://www.mouser.com/ProductDetail/490-CMS-151103-088SP
Battery | 2023-01-02 | - | 802040 | Only one battery is necessary. When using two, balance charge prior to installation. | https://www.aliexpress.us/item/3256802244810488.html

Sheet: PartsDB
Value | Package | URL
- | 802040 | https://www.aliexpress.us/item/3256802244810488.html
4.7uF | 0603 | https://www.mouser.com/ProductDetail/81-GRM188Z71A475ME5D
10uF | 0603 | https://www.mouser.com/ProductDetail/81-GRM188Z71A106KA3D
22uF | 1206 | https://www.mouser.com/ProductDetail/581-1206ZC226MAT2A
1uF | 0603 | https://www.mouser.com/ProductDetail/581-0603YC105KAT2A
100uF | 1206 | https://www.mouser.com/ProductDetail/581-TLJA107M10R1400
18pF | 0603 | https://www.mouser.com/ProductDetail/581-06035A180J
0.22uF | 0603 | https://www.mouser.com/ProductDetail/603-AC0603X7R9BB224
22pF | 0603 | https://www.mouser.com/ProductDetail/581-06035C220JAT2A
100pF | 0603 | https://www.mouser.com/ProductDetail/581-0603YC101KAT2A
27pF | 0603 | https://www.mouser.com/ProductDetail/581-06035A270J
100nF | 0603 | https://www.mouser.com/ProductDetail/581-06035C104KAT2A
LED | 0603
2.5A | 1206 | https://www.mouser.com/ProductDetail/667-ERB-RG2R50V
1A | 0603 | https://www.mouser.com/ProductDetail/594-MFU0603FF01000P1
FBx4 | 1206 | https://www.mouser.com/ProductDetail/81-BLA3216A601SG4
Link port | -
Cartridge slot | -
62684-502100ALF | 62684-502100ALF | https://www.mouser.com/ProductDetail/649-62684-502100ALF
JST PH 2-pin | -
USB4105-GF-A | GCT_USB4105-GF-A | https://www.mouser.com/ProductDetail/640-USB4105-GF-A
SJ2-3593D-SMT-TR | SJ23593DSMTTR | https://www.mouser.com/ProductDetail/490-SJ2-3593D-SMT-TR
VLS3012HBX-2R2M-N | VLS3012 | https://www.mouser.com/ProductDetail/810-VLS3012HBX2R2M-N
DMP6350SQ-7 | SOT-23 | https://www.mouser.com/ProductDetail/621-DMP6350SQ-7
10K | 0603 | https://www.mouser.com/ProductDetail/71-CRCW0603-5.1K-E3
100K | 0603 | https://www.mouser.com/ProductDetail/603-RC0603FR-07100KL
15K | 0603 | https://www.mouser.com/ProductDetail/Bourns/CR0603-FX-1502ELF
5.6K | 0603 | https://www.mouser.com/ProductDetail/71-CRCW0603-5.6K-E3
100 | 0603 | https://www.mouser.com/ProductDetail/603-RC0603FR-07100RL
150 | 0603 | https://www.mouser.com/ProductDetail/603-RT0603FRE13150RL
430K | 0603 | https://www.mouser.com/ProductDetail/603-RC0603FR-13430KL
20K | 0603 | https://www.mouser.com/ProductDetail/603-RC0603FR-0720KL
47K | 0603 | https://www.mouser.com/ProductDetail/603-RC0603FR-0747KL
1.5M | 0603 | https://www.mouser.com/ProductDetail/71-CRCW0603-1.5M-E3
200K | 0603 | https://www.mouser.com/ProductDetail/603-RC0603FR-07200KL
3.3K | 0603 | https://www.mouser.com/ProductDetail/71-CRCW0603-3.3K-E3
49.9K | 0603 | https://www.mouser.com/ProductDetail/71-CRCW0603-49.9K-E3
2.2K | 0603 | https://www.mouser.com/ProductDetail/71-CRCW0603-2.2K-E3
5.1K | 0603 | https://www.mouser.com/ProductDetail/71-CRCW0603-5.1K-E3
1K | 0603 | https://www.mouser.com/ProductDetail/652-CR0603FX-1001ELF
270x4 | 1206 | https://www.mouser.com/ProductDetail/603-TC164-JR-07270RL
SKRTLAE010 | SW_SKRTLAE010 | https://www.mouser.com/ProductDetail/688-SKRTLA
CMS-151103-088SP | - | https://www.mouser.com/ProductDetail/490-CMS-151103-088SP
SKRRAAE010 | - | https://www.mouser.com/ProductDetail/688-SKRRAA
CGB CPU | -
MAX16054AZT+T | SOT-23-6 | https://www.mouser.com/ProductDetail/700-MAX16054AZTT
CGB RAM | -
BQ24072TRGTR | VQFN-16 | https://www.mouser.com/ProductDetail/595-BQ24072TRGTR
TPS61202DSC | WSON-10 | https://www.mouser.com/ProductDetail/595-TPS61202DSCR
LM4875MM_NOPB | VSSOP-8 | https://www.mouser.com/ProductDetail/926-LM4875MM-NOPB
MCP1700T-3302E/TT | SOT-23 | https://www.mouser.com/ProductDetail/579-MCP1700T3302E-TT
TLV803EB33VDBZR | SOT-23 | https://www.mouser.com/ProductDetail/595-TLV803EB33VDBZR
TLV3201AIDBVR | SOT-23-5 | https://www.mouser.com/ProductDetail/595-TLV3201AIDBVR
RK08H113003Q | RK08H113003Q | https://www.mouser.com/ProductDetail/688-RK08H113003Q
8.388608MHz | -
8.388608MHz | 5x7Crystal | https://www.aliexpress.us/item/3256805403138830.html
OWS-111535LA-8H | - | https://www.digikey.com/en/products/detail/ole-wolff-electronics-inc/OWS-111535LA-8H/17634911

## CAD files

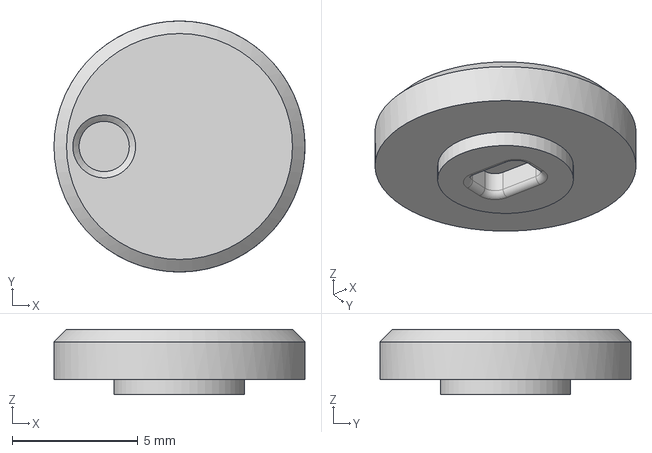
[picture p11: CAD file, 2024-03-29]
Accessories/fbcVolumeWheel021324.step
10.00 x 10.0 x 2.60 mm

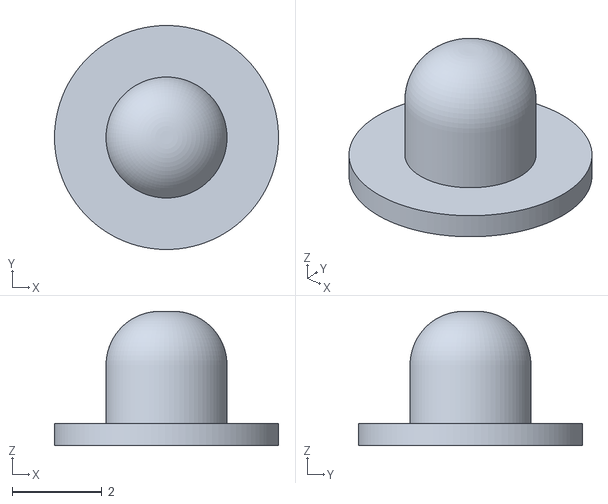
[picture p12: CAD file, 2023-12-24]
Accessories/lightPipe.stl
5.00 x 5.00 x 3.00

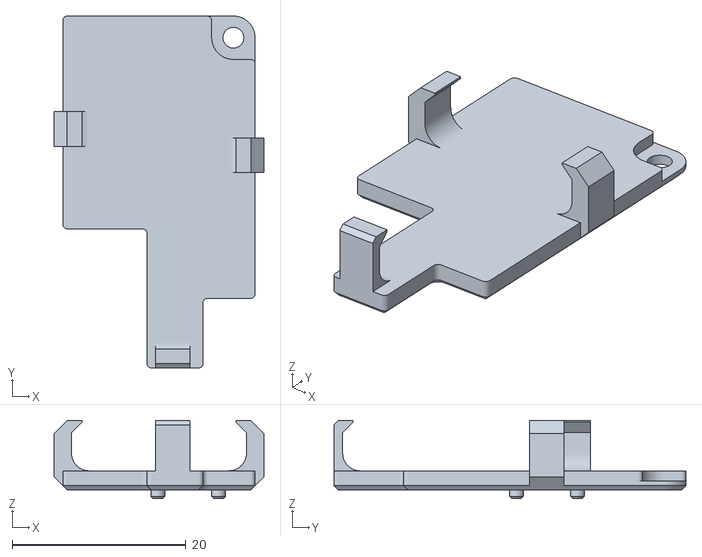
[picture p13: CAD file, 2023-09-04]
Accessories/leftBatteryClip.stl
24.1 x 40.5 x 9.00

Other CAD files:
Accessories/rightBatteryClip.stl

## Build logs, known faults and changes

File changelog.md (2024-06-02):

# 6/2/2024
## Bill of Materials/PCB
- Added footprints for spring contact speakers in place of wired speakers
- Removed battery connector footprints
- Added X1 as an alternative oscillator in place of Y1 harvested from the GBC

# 3/29/2024
## Shell
- Button wells reduced in depth by 0.5mm
- Screen cutout fillet increased to better match FunnyPlaying lens
- Screen cutout size adjusted to better fit HISPEEDIDO AMOLED kit lens
- Clearance on power button increased to better accomodate RetroCNC brightness button
- Outer and inner openings for volume wheel slightly increased for better clearance
- Cartridge shield posts adjusted to reduce outward angling of cartridges
- Clearance on screw holes slightly increased

## Volume wheel
- Redesigned with a single divot on the top face
- Height reduced to sit closer to the board
- Added technical drawing with measurements and knurling instructions

## Bill of Materials
- R17 and R19 values adjusted to ensure sound shutoff at lowest volume level

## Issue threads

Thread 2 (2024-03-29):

Release shell and PCB/Schematic files?

Helder1981, 2024-03-29:
Do you have any plans to release the step files not STL files of the shell and the actual PCB/Schematic KiCad files and not just the gerbers? It's hard to make alterations if these are not available.

Thanks.

leggomyfroggo, 2024-03-29:
No, it's not really an open source project at the moment.

Closed 2024-03-29.

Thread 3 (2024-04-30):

New scroll wheel

Dsauced8, 2024-04-30:
I put the frogboy together but the updated scroll wheel doesn’t attach do I need to cut around the area to put the scroll wheel on?

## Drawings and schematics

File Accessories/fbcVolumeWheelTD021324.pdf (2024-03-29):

.6 Ø5.2 | Ø10 around this surface 1mm pitch diamond knurling

1.75 2.6 3. All units in mm ². Note knurling requirements around outer edge 1. Debur Requirements:

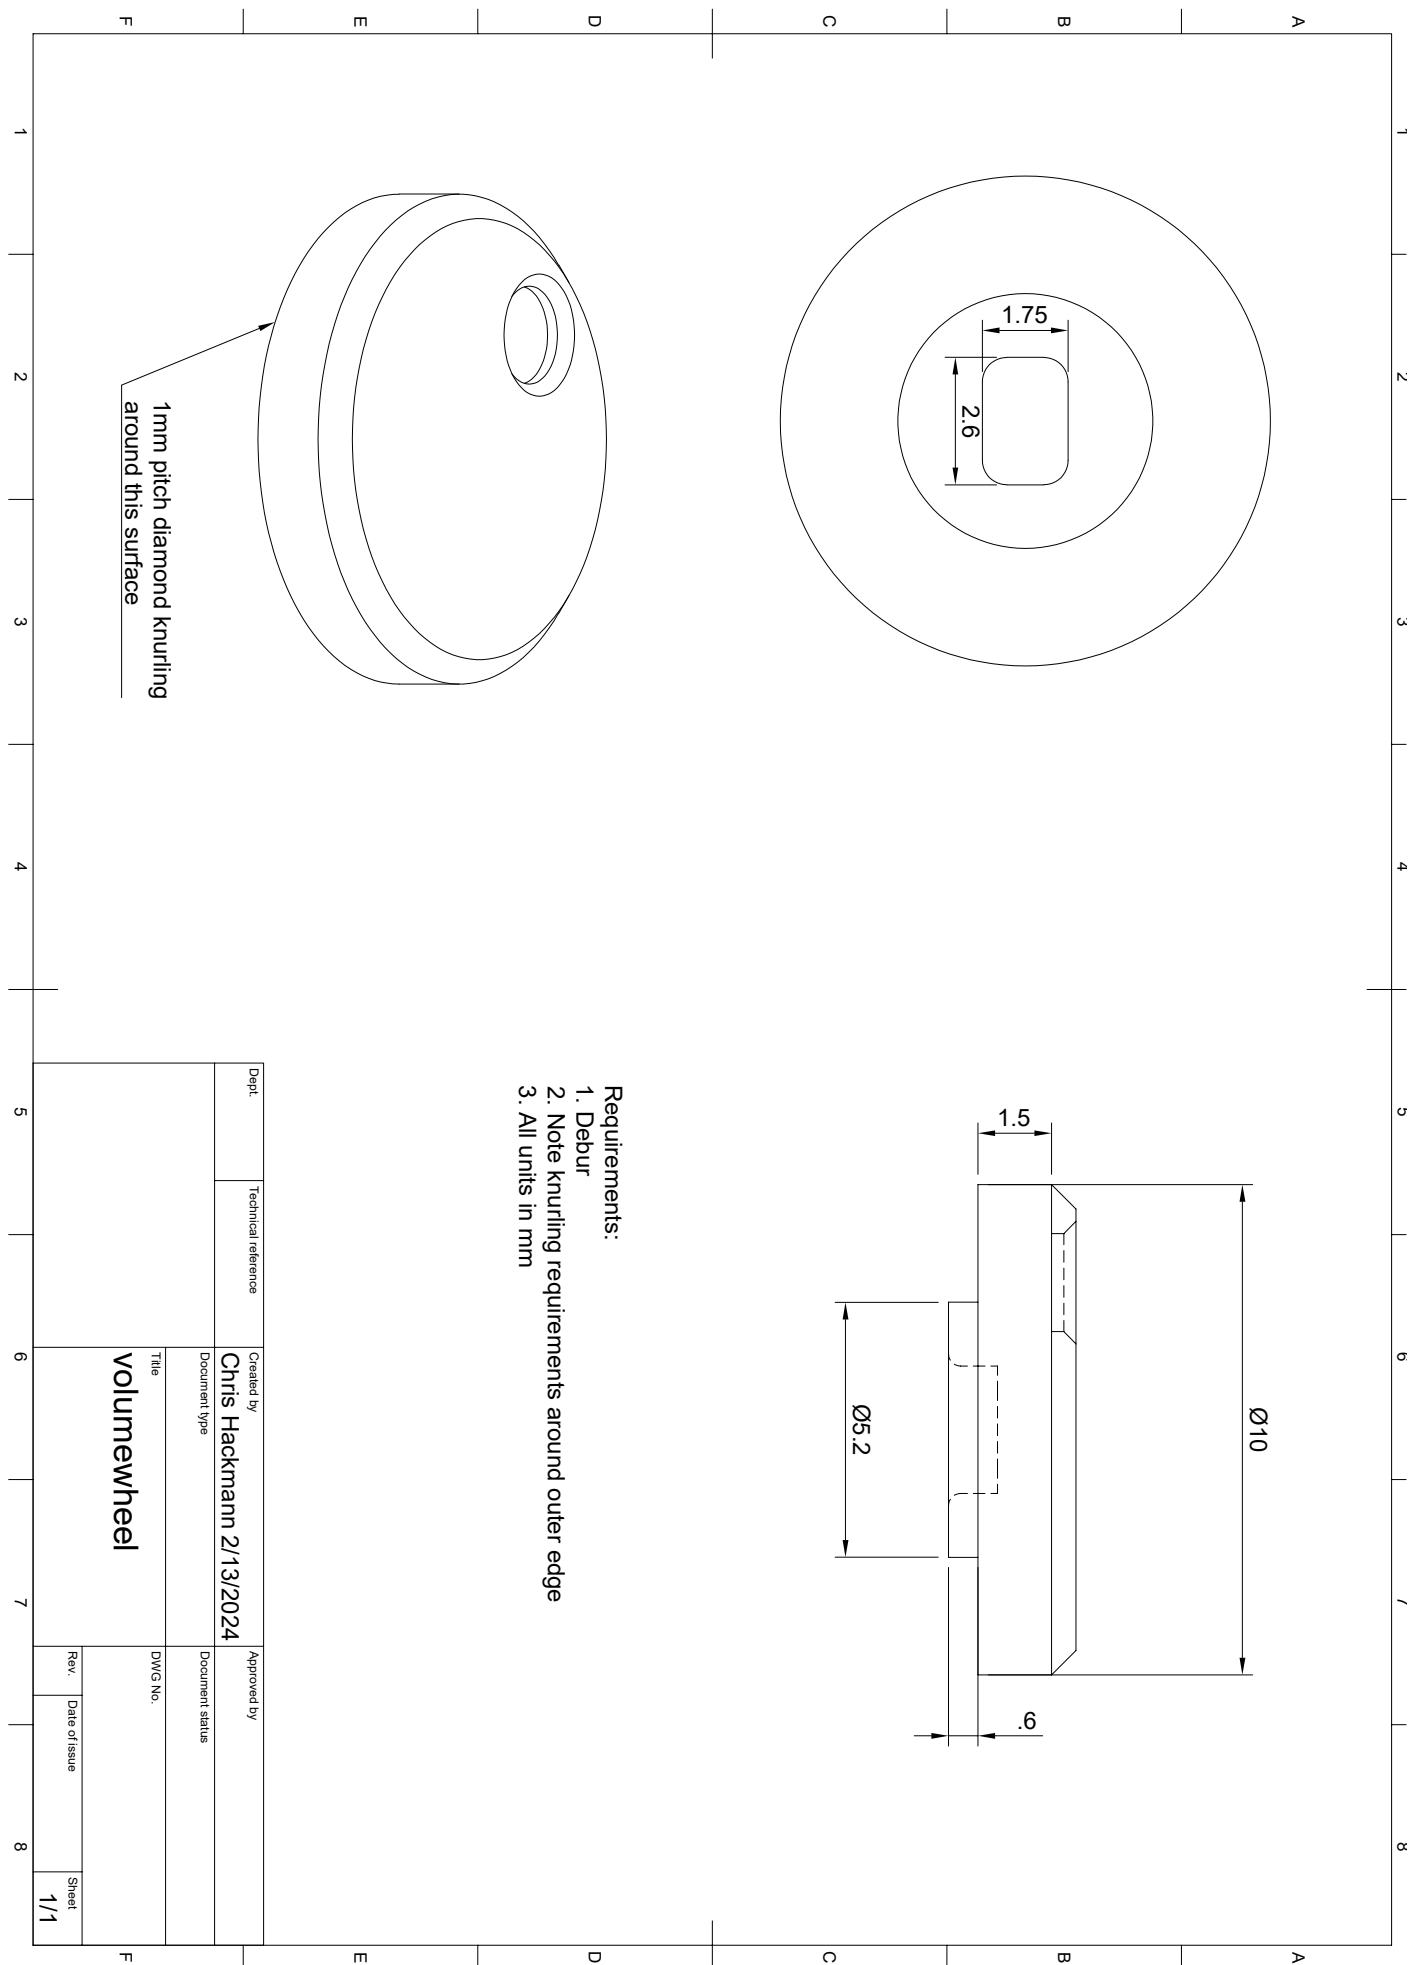
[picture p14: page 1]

1 A 2 3 4 5 6 7 8 1 2 3 4 5 6 7 8 FEDCB FEDCBA Dept. Technical reference Created by Approved by Title DWG No. Document type Document status Rev. Date of issue Sheet 2/13/2024 1/1 volumewheel Chris Hackmann

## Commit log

2023-08-29 Update README.md
    Added a lot of the assembly and BOM skeleton.
2023-08-29 Power test photos
2023-08-29 Battery parts diagram
2023-08-30 Battery circuit photos
2023-08-31 BOM excel file
    [fbcBOM.xlsx]
2023-09-04 Add STLs for battery clips and the volume knob
    [leftBatteryClip.stl, rightBatteryClip.stl, volumeKnob.stl]
2023-09-04 Added bit about battery clips
2023-09-04 Added board parameters
2023-09-04 Update README.md
    Reformatted build BOM.
2023-09-04 Add PCB BOM info
2023-10-03 Updated designators from least to greatest
    [fbcBOM.xlsx]
2023-12-24 Updated images and accessory files
    [fbcBOM.xlsx, lightPipe.stl, volumeKnob.stl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]
2023-12-24 Renamed Accessories folder and added some stuff
    [leftBatteryClip.stl, lightPipe.stl, rightBatteryClip.stl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]
2023-12-24 Update README.md
    Additional assembly details.
2023-12-24 Update README.md
    PCBWay links
2024-02-15 Add gerbers for OSD ribbon replacement
2024-03-29 Added changelog; updated accessories; updated bom
    [fbcBOM.xlsx, fbcVolumeWheel021324.step, volumeWheel.step]
2024-04-01 Fixed R19 on BOM
    [fbcBOM.xlsx]
2024-04-05 Fix sizes for some items in the BOM
    [fbcBOM.xlsx]
2024-06-02 Update BOM for new PCB
    [fbcBOM.xlsx]
